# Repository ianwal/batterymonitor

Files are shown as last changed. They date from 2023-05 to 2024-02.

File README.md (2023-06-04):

<div align="center">
  
  
  
  
  
  Wi-Fi battery monitor using a custom [ESP32-C3](https://www.espressif.com/sites/default/files/documentation/esp32-c3-wroom-02_datasheet_en.pdf) board
  
</div>

---
## About:

I drive a Crown Victoria Police Interceptor. It is *old*. The only way I can tell if it has issues is through the instrument cluster.

When I don't drive for extended periods, the battery can drain to a harmful level. I needed an alert system for when the battery needs charging to avoid killing it (again, oops).

But, third-party battery monitor systems require a nearby Phone and Bluetooth. This is a problem.

#### Solution: Build my own!

## Hardware:
#### Features:
- GPIO screw terminal block with adjustable voltage divider
- [Low Iq LDO regulator](https://www.diodes.com/assets/Datasheets/AP7361C.pdf)
- [High accuracy temperature sensor](https://www.ti.com/lit/ds/symlink/tmp235-q1.pdf)
- USB-C
- Direct USB Serial/JTAG control without a USB to UART IC

The PCB was fabricated through [JLCPCB](https://jlcpcb.com/)
- JLCPCB's assembly service does not have the required components in their inventory. I assembled mine myself.

Components were ordered from [Mouser Electronics](https://www.mouser.com). You can find the complete bill of materials in the KiCad project.

## Software:
#### Features:
- Deep sleep to reduce power consumption

#### Setup:

Clone the repository and flash the microcontroller using the PlatformIO IDE Visual Studio Code extension.

Fill in your Home Assistant URL, Long Lived Access Token, Wi-Fi SSID, and Wi-Fi Password in `include/secrets.h`

#### Dependencies:
- [esp-ha-lib](https://github.com/ianwal/esp-ha-lib)
- FreeRTOS

You can modify the program to use a web server other than [Home Assistant](https://www.home-assistant.io/) easily. I use it for other IOT devices, so it was useful to incorporate into this project.

## Performance:

Voltage accuracy is around ± 0.1 V

Power consumption is still being evaluated

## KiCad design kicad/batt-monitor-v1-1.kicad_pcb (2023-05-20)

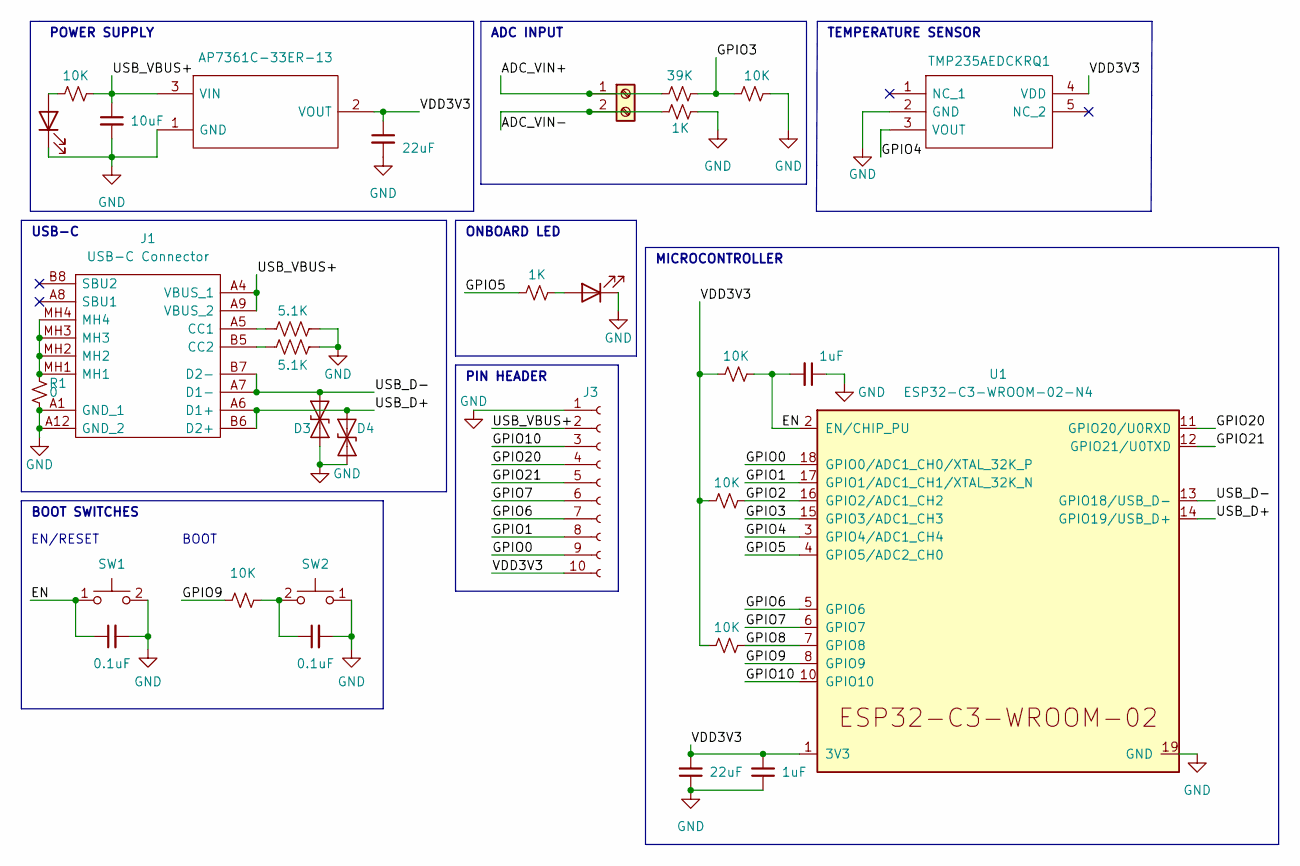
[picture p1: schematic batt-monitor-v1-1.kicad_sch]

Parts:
C1: 10uF; C_0603_1608Metric; LCSC C15849
C2, C3: 0.1uF; C_0603_1608Metric; LCSC C15849
C4, C5: 22uF; C_0603_1608Metric; LCSC C59461
C6, C7: 1uF; C_0603_1608Metric; LCSC C15849
D1, D2: LED; LED_0603_1608Metric; Mouser 710-150060RS75000
D3, D4: ESD9B5.0ST5G; D_SOD-923
IC1: AP7361C-33ER-13; SOT230P700X180-4N; Manufacturer_Part_Number AP7361C-33ER-13; Mouser Part Number 621-AP7361C-33ER-13
IC2: TMP235AEDCKRQ1; SOT65P210X110-5N; Manufacturer_Part_Number TMP235AEDCKRQ1; Mouser Part Number 595-TMP235AEDCKRQ1
J1: USB-C Connector; 2169900002; Manufacturer_Part_Number 2169900002
J2: Screw_Terminal_01x02; TB00250002BE; LCSC C8475
J3: Conn_01x10_Female; PinHeader_1x10_P2.54mm_Vertical
R1: 0; R_0603_1608Metric
R2, R3, R11, R12, R13, R14: 10K; R_0603_1608Metric; LCSC C25197
R4: 5.1K; R_0603_1608Metric; LCSC C23193
R5: 5.1K; R_0603_1608Metric
R6: 1K; R_0603_1608Metric
R9: 39K; R_0603_1608Metric; LCSC C23151
R10: 1K; R_0603_1608Metric; LCSC C22775
SW1, SW2: SW_Push; SW_SPST_TL3305A; Mouser 612-TL3305AF260QG
U1: ESP32-C3-WROOM-02-N4; ESP32-C3-WROOM-02

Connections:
/ADC_VIN+: J2.1, R9.1
/ADC_VIN-: J2.2, R10.1
/EN: C2.1, C7.2, R14.2, SW1.1, U1.2 (EN/CHIP_PU); also elsewhere on the board
/GPIO0: J3.9, U1.18 (GPIO0/ADC1_CH0/XTAL_32K_P)
/GPIO1: J3.8, U1.17 (GPIO1/ADC1_CH1/XTAL_32K_N)
/GPIO2: R12.2, U1.16 (GPIO2/ADC1_CH2)
/GPIO3: R9.2, R11.1, U1.15 (GPIO3/ADC1_CH3)
/GPIO4: IC2.3 (VOUT), U1.3 (GPIO4/ADC1_CH4)
/GPIO5: R6.1, U1.4 (GPIO5/ADC2_CH0)
/GPIO6: J3.7, U1.5 (GPIO6)
/GPIO7: J3.6, U1.6 (GPIO7)
/GPIO8: R13.2, U1.7 (GPIO8)
/GPIO9: R3.1, U1.8 (GPIO9)
/GPIO10: J3.3, U1.10 (GPIO10)
/GPIO20: J3.4, U1.11 (GPIO20/U0RXD)
/GPIO21: J3.5, U1.12 (GPIO21/U0TXD)
/USB_D+: D4.2 (A2), J1.A6 (D1+), J1.B6 (D2+), U1.14 (GPIO19/USB_D+)
/USB_D-: D3.2 (A2), J1.A7 (D1-), J1.B7 (D2-), U1.13 (GPIO18/USB_D-)
/USB_VBUS+: C1.1, IC1.3 (VIN), J1.A4 (VBUS_1), J1.A9 (VBUS_2), J3.2, R2.2
/VDD3V3: C4.1, C5.2, C6.2, IC1.2 (VOUT), IC2.4 (VDD), J3.10, R12.1, R13.1, R14.1, U1.1 (3V3)
GND: C1.2, C2.2, C3.2, C4.2, C5.1, C6.1, C7.1, D1.1 (K), D2.1 (K), D3.1 (A1), D4.1 (A1), IC1.1 (GND), IC2.2 (GND), J1.A1 (GND_1), J1.A12 (GND_2), J3.1, R1.2, R4.2, R5.2, R10.2, R11.2, SW1.2, SW2.1, U1.9 (GND), U1.19 (GND); also elsewhere on the board
unnamed 21: C3.1, R3.2, SW2.2; also elsewhere on the board
unnamed: D1.2 (A), R2.1
unnamed: D2.2 (A), R6.2
unnamed: J1.A5 (CC1), R4.1
unnamed: J1.B5 (CC2), R5.1
unnamed: J1.MH1, J1.MH2, J1.MH3, J1.MH4, R1.1

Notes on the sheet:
ONBOARD LED
ADC INPUT
BOOT
MICROCONTROLLER
EN/RESET
USB-C
BOOT SWITCHES
POWER SUPPLY
TEMPERATURE SENSOR
PIN HEADER

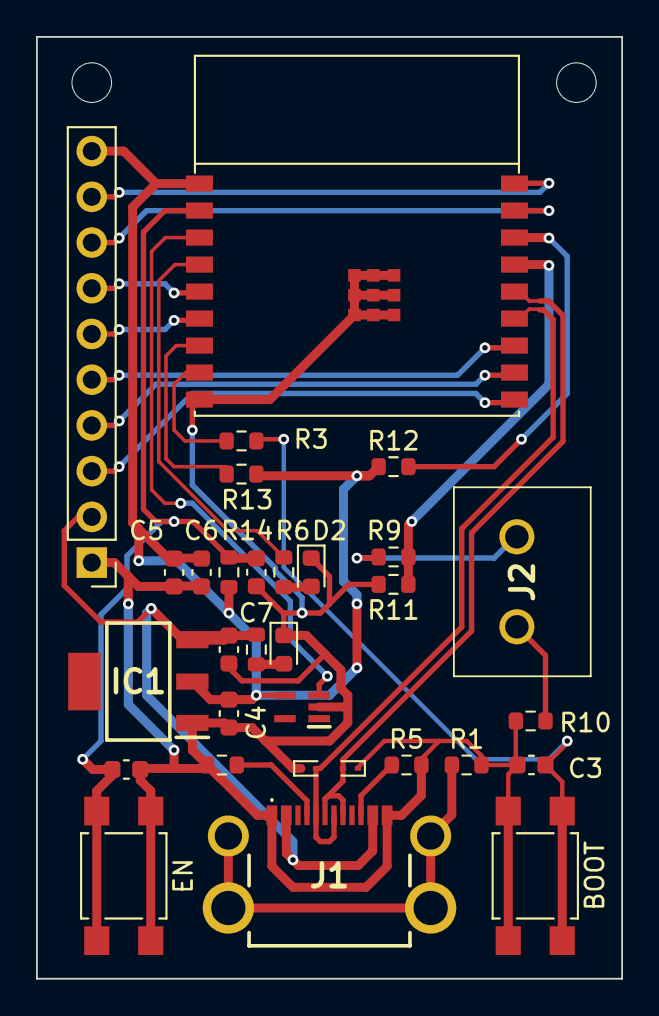
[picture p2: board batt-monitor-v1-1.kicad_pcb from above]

Board: 2 copper layers, 32.5 x 52.3 mm, 31 parts (0 on the bottom side), 27 nets.

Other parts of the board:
BOOT: SW_Push; SW_SPST_TL3305A
EN: SW_Push; SW_SPST_TL3305A

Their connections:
/EN: EN.1; also elsewhere on the board
GND: BOOT.1, EN.2; also elsewhere on the board
unnamed 21: BOOT.2; also elsewhere on the board

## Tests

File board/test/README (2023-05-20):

This directory is intended for PlatformIO Test Runner and project tests.

Unit Testing is a software testing method by which individual units of
source code, sets of one or more MCU program modules together with associated
control data, usage procedures, and operating procedures, are tested to
determine whether they are fit for use. Unit testing finds problems early
in the development cycle.

More information about PlatformIO Unit Testing:
- https://docs.plat/home/alf/Documents/code/github/battmonitor/board/battmonitor/src/formio.org/en/latest/advanced/unit-testing/index.html

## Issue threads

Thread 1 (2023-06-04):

Legacy ADC driver is deprecated in ESP-IDF 5.0

ianwal, 2023-06-04:
battery.c uses the legacy ADC driver `driver/adc.h` while ESP-IDF has developed a new driver in `esp_adc`. Update the old battery reading to use the new oneshot ADC driver.

https://docs.espressif.com/projects/esp-idf/en/v5.0.2/esp32s2/migration-guides/release-5.x/peripherals.html

ianwal, 2023-06-06:
Fixed by d2286a0

Closed 2023-06-06.

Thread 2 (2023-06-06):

USB-C part is not compatible with PCB without modification

ianwal, 2023-06-06:
I had to bend the leads on the USB-C connector that I bought and clip off the rubber feet on the bottom. Need to find a replacement part.

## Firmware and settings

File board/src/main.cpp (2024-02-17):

#ifndef PROJECTIO_TESTING

extern "C" {
#include "esp_log.h"
#include "esp_sleep.h"
#include "freertos/FreeRTOS.h"
#include "freertos/event_groups.h"
#include "freertos/task.h"
}

#include <chrono>
#include "battery.hpp"
#include "esp_ha_lib.hpp"
#include "nvs_control.hpp"
#include "secrets.h"
#include "utils.h"
#include "wifi.h"
#include <cstring>

namespace BatteryMonitor
{

namespace
{

constexpr auto TAG{"Main"};
constexpr std::chrono::minutes TIME_IN_DEEP_SLEEP{1};
constexpr std::chrono::seconds TIME_UNTIL_DEEP_SLEEP{10};

// Read and upload battery data to Home Assistant.
void upload_battery_task(void *args)
{
        while (1) {
                auto const battery_entity = create_battery_entity();

                ESP_LOGI(TAG, "Waiting for Wi-Fi to upload battery...");
                if (Wifi::wait_wifi_connected(Utils::to_ticks(std::chrono::seconds{5}))) {
                        ESP_LOGI(TAG, "Uploading battery to %s", Secrets::HA_URL.data());
                        battery_entity->post();
                        ESP_LOGI(TAG, "Battery upload attempted.");
                } else {
                        ESP_LOGI(TAG, "upload_battery timed out. Retrying...");
                }
                battery_entity->print();
                vTaskDelay(Utils::to_ticks(std::chrono::seconds{1}));
        }
}

// Start Wi-Fi state machine.
void start_wifi_task(void *args)
{
        while (1) {
                Wifi::wifi_init_station();
                vTaskSuspend(NULL);
        }
}

// Turn off peripherals and enters deep sleep
void start_deep_sleep()
{
        ESP_LOGI(TAG, "Shutting down peripherals.");
        ESP_LOGI(TAG, "Stopping Wi-Fi.");
        Wifi::stop_wifi();

        ESP_LOGI(TAG, "Entering Deep Sleep");
        esp_deep_sleep_start();
}

} // namespace


extern "C" {
void app_main(void)
{
        // Init non-volatile storage (for Wi-Fi).
        {
            auto const is_nvs_init_success = Nvs::init_nvs();
            if (!is_nvs_init_success) {
                    ESP_LOGI(TAG, "Entering Deep Sleep due to NVS init failure. Monitor has failed.");
                    esp_deep_sleep_start();
            }
        }

        // Setup Home Assistant info.
        {
            static_assert(!Secrets::LONG_LIVED_ACCESS_TOKEN.empty());
            static_assert(!Secrets::HA_URL.empty());
            static_assert(Secrets::HA_URL.back() != '/', "HA URL must not have a leading slash.");
            esphalib::api::set_ha_url(Secrets::HA_URL.data());
            esphalib::api::set_long_lived_access_token(Secrets::LONG_LIVED_ACCESS_TOKEN.data());
        }

        // Main.
        {
            ESP_LOGI(TAG, "Enabling sleep timer wakeup: %lld minutes until wakeup. \n", TIME_IN_DEEP_SLEEP.count());
            ESP_ERROR_CHECK_WITHOUT_ABORT(esp_sleep_enable_timer_wakeup(std::chrono::duration_cast<std::chrono::microseconds>(TIME_IN_DEEP_SLEEP).count()));

            // Connect to Wi-Fi.
            TaskHandle_t wifi_task_handle = nullptr;
            xTaskCreate(start_wifi_task, "start wifi task", 4096, nullptr, 5, &wifi_task_handle);

            // Upload sensor data.
            TaskHandle_t upload_battery_task_handle = nullptr;
            xTaskCreate(upload_battery_task, "upload battery task", 4096, nullptr, 1, &upload_battery_task_handle);

            // Go to deep sleep after a set amount of time.
            vTaskDelay(Utils::to_ticks(TIME_UNTIL_DEEP_SLEEP));
            ESP_LOGI(TAG, "Deep Sleep timeout reached");

            // NOTE: Tasks don't need to be cleaned up because deep sleep will reset the device and clear RAM.
            start_deep_sleep();
        }
}
}

} // namespace BatteryMonitor

#endif

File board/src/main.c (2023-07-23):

#ifndef PROJECTIO_TESTING
#include <stdbool.h>
#include <string.h>

#include "esp_event.h"
#include "esp_http_client.h"
#include "esp_log.h"
#include "esp_sleep.h"
#include "esp_system.h"
#include "esp_wifi.h"
#include "freertos/FreeRTOS.h"
#include "freertos/event_groups.h"
#include "freertos/task.h"
#include "nvs_flash.h"

#include "lwip/err.h"
#include "lwip/sys.h"

#include "driver/gpio.h"

#include "battery.h"
#include "esp_ha_lib.h"
#include "secrets.h"
#include "wifi.h"

static const char *TAG = "Main";
static const uint64_t WAKEUP_TIME_SEC = 1800;
static const uint32_t HARD_SLEEP_TIMEOUT_SEC = 10;

HAEntity *battery_entity = NULL;

void init_nvs()
{
        esp_err_t ret = nvs_flash_init();
        if (ret == ESP_ERR_NVS_NO_FREE_PAGES || ret == ESP_ERR_NVS_NEW_VERSION_FOUND) {
                ESP_ERROR_CHECK(nvs_flash_erase());
                ret = nvs_flash_init();
        }
        ESP_ERROR_CHECK(ret);
}

// Read and upload battery.
static void upload_battery_task(void *args)
{
        while (1) {
                battery_entity = get_battery_entity();
                if (!battery_entity) {
                        ESP_LOGE(TAG, "Failed to get battery entity.");
                        vTaskDelay(pdMS_TO_TICKS(5000));
                        continue;
                }

                HAEntity_print(battery_entity);
                ESP_LOGI(TAG, "Waiting for Wi-Fi to upload battery...");
                if (wait_wifi_connected(pdMS_TO_TICKS(2000))) {
                        ESP_LOGI(TAG, "Uploading battery to %s", HA_URL);
                        post_entity(battery_entity);
                        ESP_LOGI(TAG, "Battery upload attempted.");
                } else {
                        ESP_LOGI(TAG, "upload_battery timed out. Retrying...");
                }
                HAEntity_delete(battery_entity);
                vTaskDelay(pdMS_TO_TICKS(1000));
        }
}

// Turn off peripherals and enters deep sleep
static void start_deep_sleep()
{
        ESP_LOGI(TAG, "Shutting down peripherals.");
        ESP_LOGI(TAG, "Stopping Wi-Fi.");
        stop_wifi();

        ESP_LOGI(TAG, "Entering Deep Sleep");
        esp_deep_sleep_start();
}

// Connects to Wi-Fi and suspends
static void start_wifi_task(void *args)
{
        while (1) {
                wifi_init_sta();
                vTaskSuspend(NULL);
        }
}

void app_main(void)
{
        init_nvs();

        set_ha_url(HA_URL);
        set_long_lived_access_token(LONG_LIVED_ACCESS_TOKEN);

        ESP_LOGI(TAG, "Enabling timer wakeup, %llds\n", WAKEUP_TIME_SEC);
        ESP_ERROR_CHECK(esp_sleep_enable_timer_wakeup(WAKEUP_TIME_SEC * 1000000));

        // Connect to Wi-Fi
        TaskHandle_t wifi_task_handle = NULL;
        xTaskCreate(start_wifi_task, "start wifi task", 4096, NULL, 5, &wifi_task_handle);

        // Upload battery
        TaskHandle_t upload_battery_task_handle = NULL;
        xTaskCreate(upload_battery_task, "upload battery task", 8192, NULL, 1, &upload_battery_task_handle);

        // Calls deep sleep after a set amount of time
        vTaskDelay(pdMS_TO_TICKS(HARD_SLEEP_TIMEOUT_SEC * 1000));
        ESP_LOGI(TAG, "Deep Sleep timeout reached");

        // Tasks don't need to be cleaned up because
        // deep sleep will reset the device and clear RAM
        start_deep_sleep();
}
#endif

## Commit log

2023-05-20 Initial upload from old repo
    [batt-monitor-v1-1.kicad_pcb, batt-monitor-v1-1.kicad_sch]
2023-05-24 Added ESP32C3 support
    - Also fixed wrong function name from new esp-ha-lib update
    [main.c]
2023-05-24 Moved adc battery read logic to separate function
2023-06-04 Update function name from esp-ha-lib
    Also added a check for null get_entity in sensor_upload test
2023-06-04 Add Battery TAG name for logging
2023-06-04 Decrease time not in deep sleep
    - Remove deep sleep timer since it's only used for debugging currently
    - Remove NVS init since only the timer needed it
    WiFi does NVS init in wifi_init_sta() for itself
2023-06-06 Update ADC to new driver
    * See more information [here](https://docs.espressif.com/projects/esp-idf/en/v5.0.2/esp32s2/migration-guides/release-5.x/peripherals.html)
2023-06-10 Improve resilience to WiFi failure
    * Move WiFi startup and battery reading to tasks
    * Attempt upload multiple times before sleeping
    * Set default WiFi condition to disconnected
    [main.c]
2023-06-10 Add support for line calibration
    Some older ESP32's don't support curve calibration.
2023-07-23 Move entity alloc to battery, add missing headers
    Also move nvs init from wifi to main
    [battery.c, main.c]
2024-02-17 Change gtest to Unity, add namespaces, convert wifi.c to cpp, fix compat. with newest version of esphalib, add utilities
    [battery.cpp, main.cpp]
